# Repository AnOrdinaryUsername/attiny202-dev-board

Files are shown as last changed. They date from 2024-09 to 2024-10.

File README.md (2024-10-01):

# ATtiny202 Dev Board

A small development board for the ATtiny202 microcontroller and my first PCB!

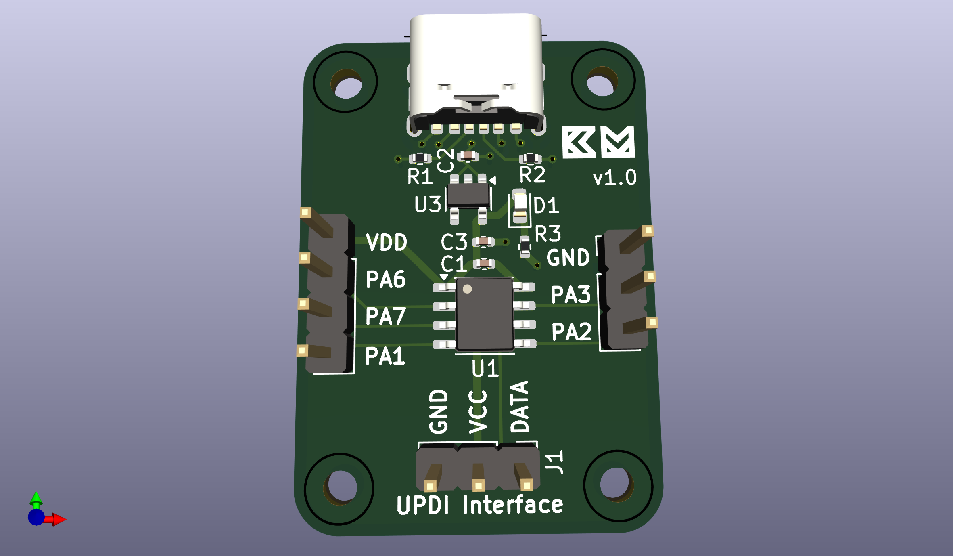
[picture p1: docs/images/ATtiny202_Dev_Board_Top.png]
PCB Top View


## Features

- Power-Only USB Type-C Receptacle
- 3.3V LDO Voltage Regulator
- Red Power On LED Indicator
- UPDI Interface

## Programming

Programmable using [SerialUPDI](https://github.com/SpenceKonde/AVR-Guidance/blob/master/UPDI/jtag2updi.md) (recommended)
or [jtag2updi](https://github.com/ElTangas/jtag2updi).

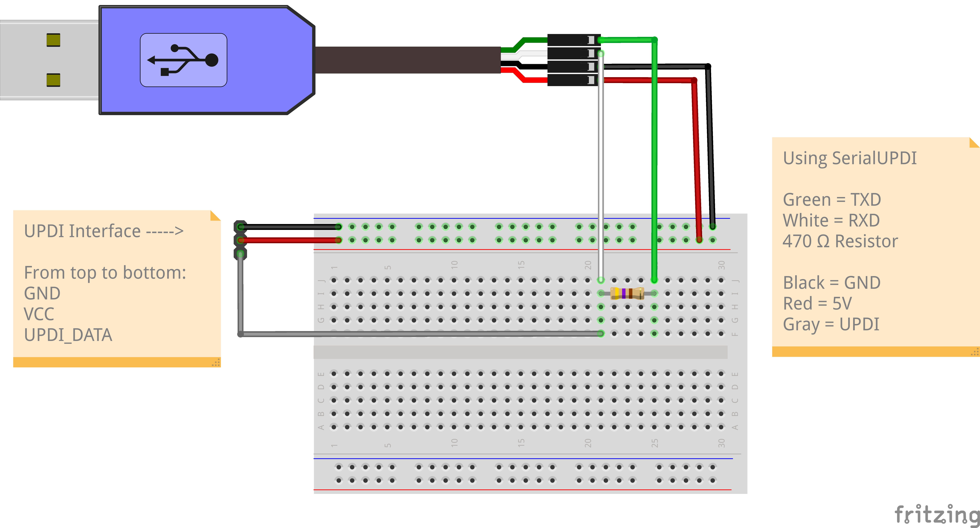
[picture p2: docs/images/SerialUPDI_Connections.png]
SerialUPDI Connections


Install avrdude following these [instructions](https://github.com/avrdudes/avrdude/wiki/Building-AVRDUDE-for-Linux) on their GitHub. Don't install through your system's package manager, or you'll get an older version of avrdude that doesn't have SerialUPDI. 

Before you can use avr-gcc to build the program, you must first download the device-pack files
from [Microchip's Packs Repository](https://packs.download.microchip.com/). Download the one that
says `Microchip ATtiny Series Device Support (3.1.260)` and then unzip it to a directory of your
choice.

```
mkdir atpack
mv Microchip.ATtiny_DFP.3.1.260.atpack atpack
cd atpack && unzip Microchip.ATtiny_DFP.3.1.260.atpack
```

You can now build specific projects using the `Makefile`

```
make build proj=blinky atpack=~/atpack/
```

Or build all projects

```
make
```

After you've built your project and connected the USB to TTL adapter to your PC and the UPDI interface, 
upload the build files using avrdude.

```
avrdude -vvv -c serialupdi -b 230400 -P /dev/ttyUSB0 -p t202 -U flash:w:your_build_file.hex:a
```

Breaking it down (better explanation at [avrdude docs](https://avrdudes.github.io/avrdude/8.0/avrdude_4.html#Option-Descriptions)):
- `-vvv` Enables verbose output
- `-c` Specifies the programmer to be used
- `-b` Sets the baud rate
- `-P` Selects which port to use
- `-p` Says which microcontroller we're programming for (t202 stands for ATtiny202). You can view the list of parts supported at [D. List of Parts](https://avrdudes.github.io/avrdude/8.0/avrdude_45.html#List-of-Parts)
- `-U` Write the hex file to flash memory and auto-detect the file format (usually Intel Hex)

Alternatively, you can also use the `Makefile`:

```
make upload proj=blinky port=/dev/ttyUSB0
```

## Schematic

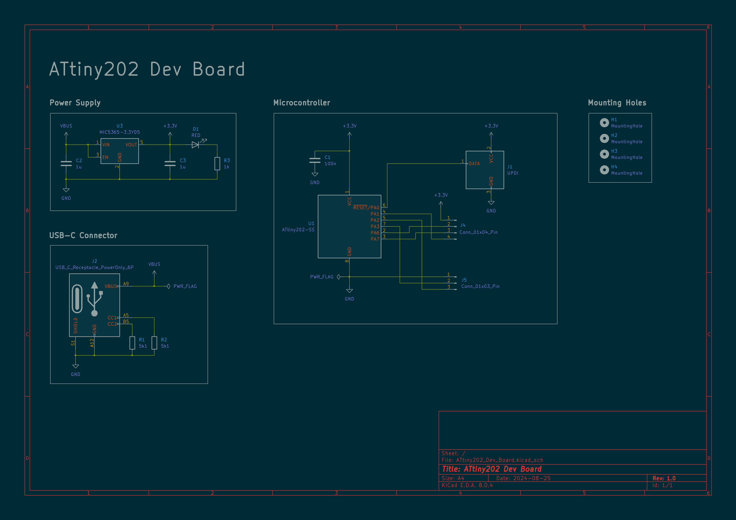
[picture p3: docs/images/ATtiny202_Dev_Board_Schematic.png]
Board Schematic


## Manufacturing/Assembly

JLCPCB formatted BOM, CPL, and Gerber files can be found in [hardware](/hardware).

Here's how the fully assembled PCB looks.

Top             |  Bottom
:-------------------------:|:-------------------------:
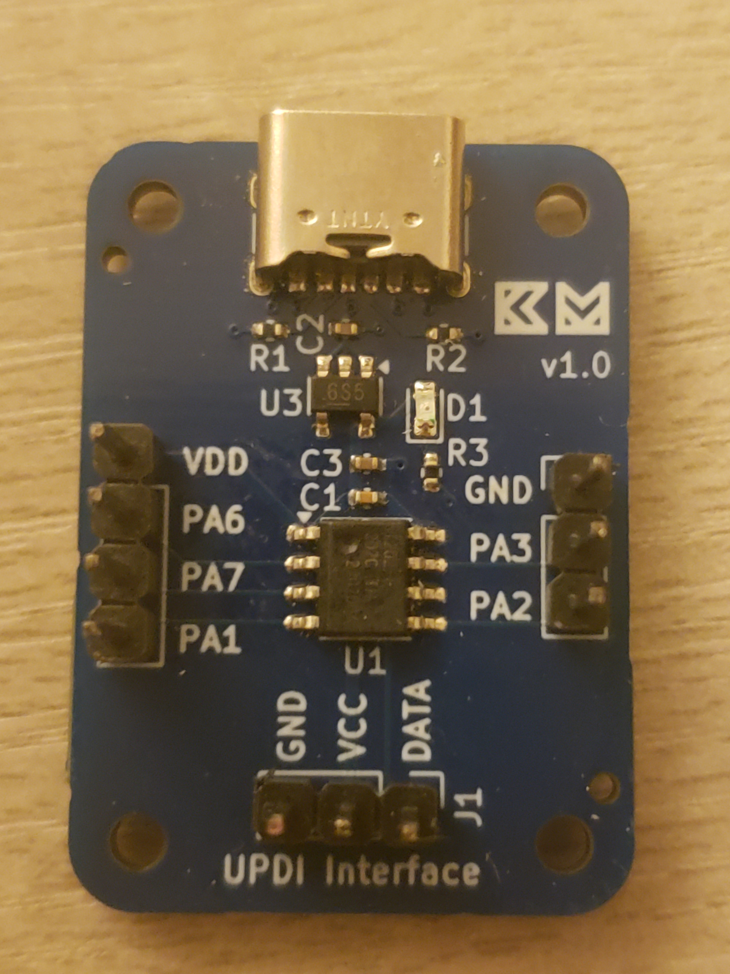
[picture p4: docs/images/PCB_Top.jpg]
Top View of PCB
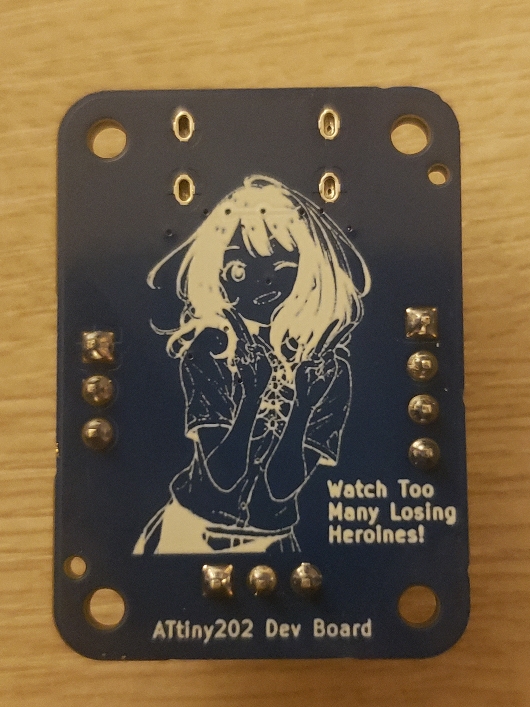
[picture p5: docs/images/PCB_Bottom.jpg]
Bottom View of PCB
 |

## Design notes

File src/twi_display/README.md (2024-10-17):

# TWI Example w/ LCD 1602

> I recommend reading A Basic Guide to I2C from Texas Instruments

Formula for SCL frequency from `25.3.4.2 TWI Master Operation`. Before starting
TWI as master, we have to set the baud rate and solve for BAUD.

```math
f_{SCL} = \frac{f_{CLK\_PER}}{10 + 2 BAUD + f_{CLK\_PER} * T_{RISE}}
```

To solve for BAUD, just plug in the values:
- CPU Clock is set to 10 MHz
- SCL is 100 kHz because we're using standard mode
- tRISE is from `31.10 I/O Pin Characteristics`

```math
\begin{multline}
\frac{f_{CLK\_PER}}{{f_{SCL}}} = 10 + 2 BAUD + f_{CLK\_PER} * T_{RISE} \\
\frac{10 MHz}{100 kHz} = 10 + 2 BAUD + 10 MHz * 2.5 ns \\
BAUD = 44.9875 \approx 45
\end{multline}
```

Minimum pullup can be calculated with the following formula.
Values taken from `Table 31-18. TWI - Timing Characteristics`.

```math
R_{P}(min) = \frac{VCC - V_{OL}(max)}{I_{OL}}
           = \frac{3.3-0.4}{3 mA}
           \approx 967 Ω
```

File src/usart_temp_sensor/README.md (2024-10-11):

# USART Example w/ On-Chip Temperature Sensor

A basic USART example that transfers on-chip temperature sensor data to your PC's terminal every
time you press a push button.

```bash
> cat /dev/ttyUSB0
Temperature (C): 27

Turning LED on

Turning LED off
```

If your sensor doesn't seem to output the right values, this could be the issue (from Errata).

Screenshot (23)

## Programming

See [programming section](https://github.com/AnOrdinaryUsername/attiny202-dev-board/blob/master/README.md#programming).

## Connections

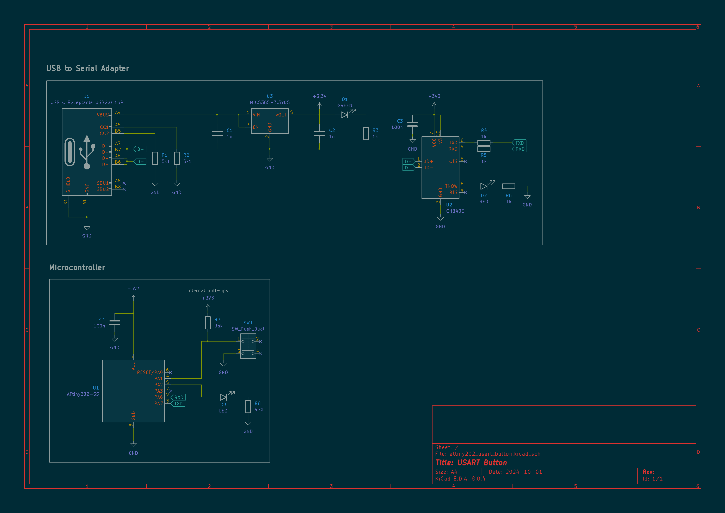
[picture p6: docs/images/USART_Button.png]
USART Button Schematic


Using a USB to Serial Adapter, make the following connections to a breadboard:
- Connect 3.3V/5V to Breadboard +
- GND to Breadboard -

On the breadboard:
- Add a button + LED with 470Ω resistor
- Breadboard - to any button pin and cathode of LED

With the dev board connect:
- VDD to Breadboard +
- GND to Breadboard -
- PA6 pin (TXD) to RXD of USB to Serial Adapter
- PA7 pin (RXD) to TXD of USB to Serial Adapter
- PA1 on button pin (near the one that was connected to ground)
- PA2 to anode of LED

Connect the adapter to your PC then run the following command

```bash
cat /dev/ttyUSB0
```

or

```bash
screen /dev/ttyUSB0 9600
```

To turn LED on or off, run
```
echo "y" > /dev/ttyUSB0
echo "n" > /dev/ttyUSB0
```

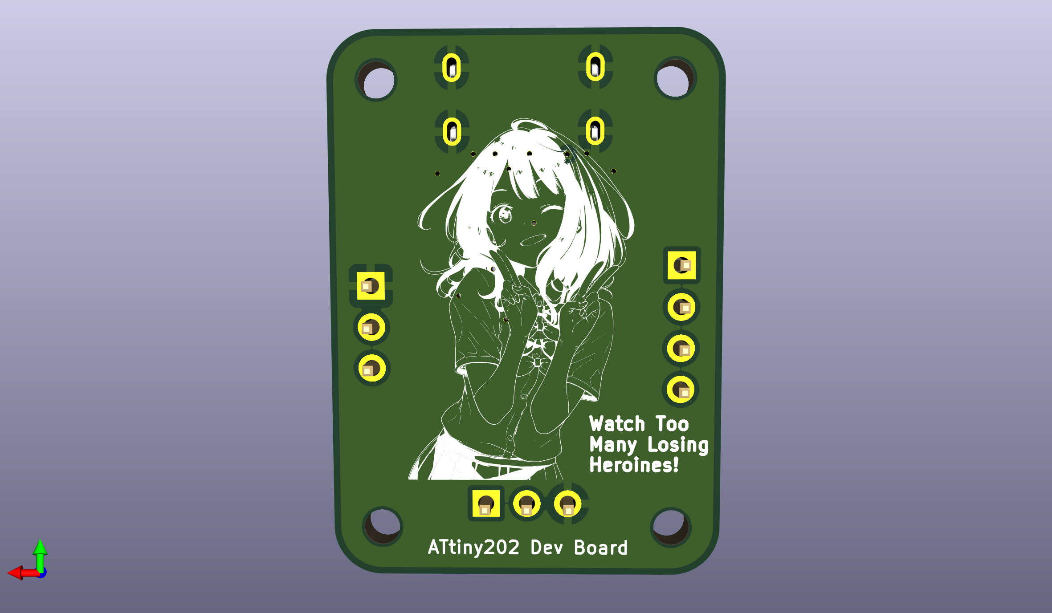
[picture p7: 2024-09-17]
docs/images/ATtiny202_Dev_Board_Bottom.png

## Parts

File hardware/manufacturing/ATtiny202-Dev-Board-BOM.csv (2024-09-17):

Comment | Designator | Qty | Footprint | JLCPCB Part #
100n | C1 | 1 | Capacitor_SMD:C_0402_1005Metric | C387941
1u | C2,C3 | 2 | Capacitor_SMD:C_0402_1005Metric | C76999
1k | R3 | 1 | Resistor_SMD:R_0402_1005Metric | C106235
5k1 | R1,R2 | 2 | Resistor_SMD:R_0402_1005Metric | C138073
ATtiny202-SS | U1 | 1 | Package_SO:SOIC-8_3.9x4.9mm_P1.27mm | C616039
Conn_01x03_Pin | J5 | 1 | Connector_PinHeader_2.54mm:PinHeader_1x03_P2.54mm_Vertical | C5360899
Conn_01x04_Pin | J4 | 1 | Connector_PinHeader_2.54mm:PinHeader_1x04_P2.54mm_Vertical | C5116483
MIC5365-3.3YD5 | U3 | 1 | Package_TO_SOT_SMD:SOT-23-5 | C626098
RED | D1 | 1 | LED_SMD:LED_0603_1608Metric | C2286
UPDI | J1 | 1 | Connector_PinHeader_2.54mm:PinHeader_1x03_P2.54mm_Vertical | C5360899
USB_C_Receptacle_PowerOnly_6P | J2 | 1 | Connector_USB:USB_C_Receptacle_GCT_USB4125-xx-x_6P_TopMnt_Horizontal | C456012

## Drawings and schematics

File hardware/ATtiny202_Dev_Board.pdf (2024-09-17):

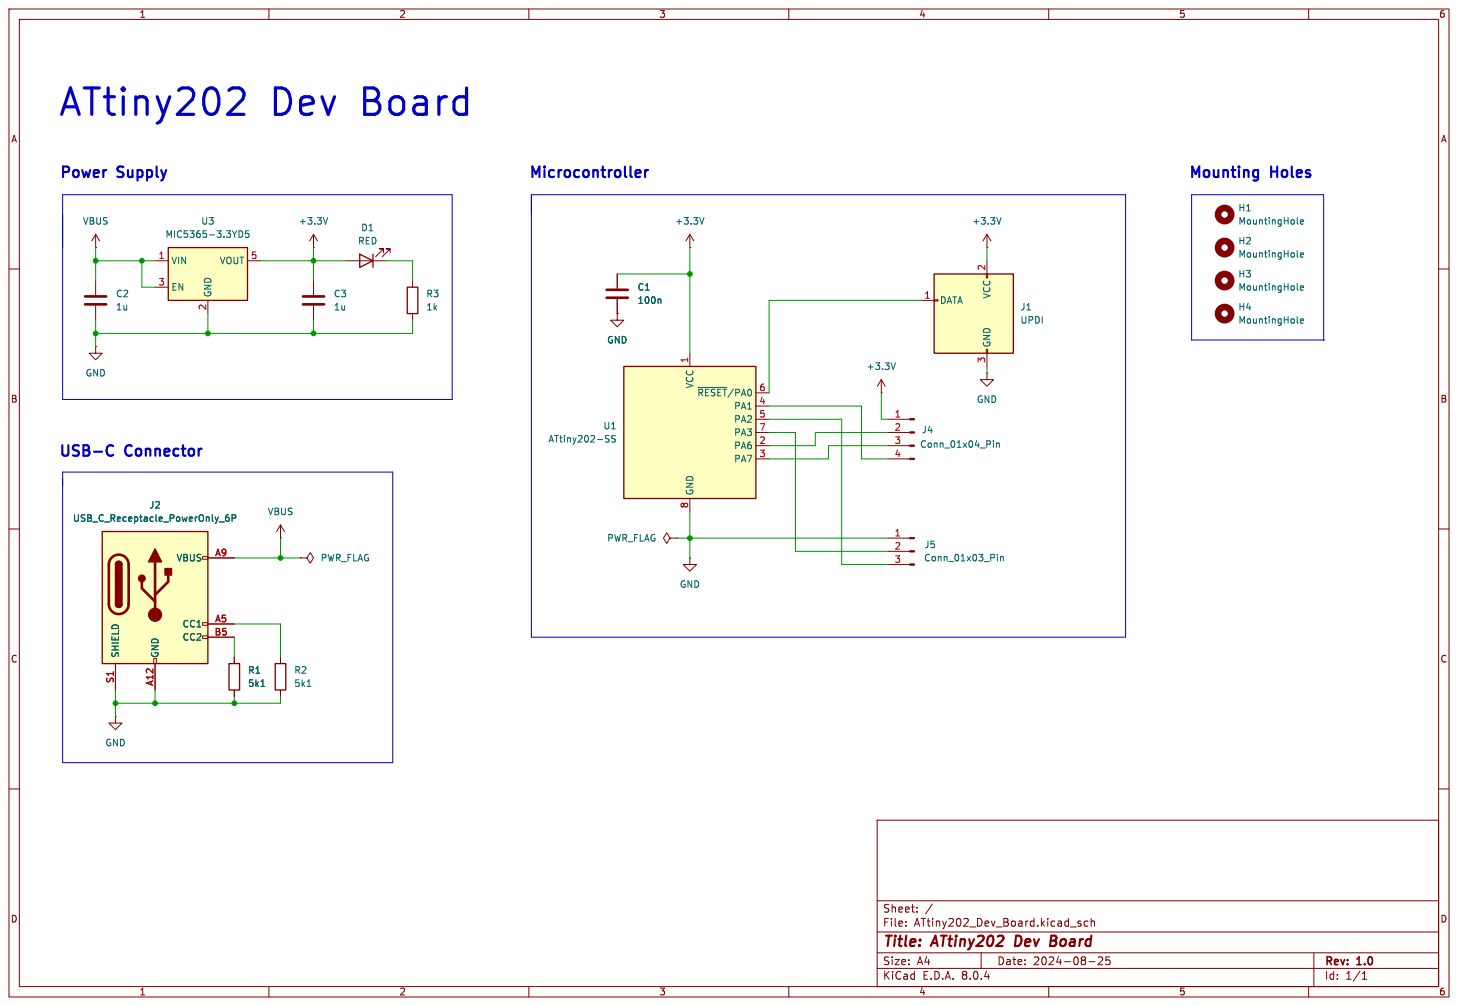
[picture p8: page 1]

File: ATtiny202_Dev_Board.kicad_sch Sheet: /
Id: 1/1 Title: ATtiny202 Dev Board

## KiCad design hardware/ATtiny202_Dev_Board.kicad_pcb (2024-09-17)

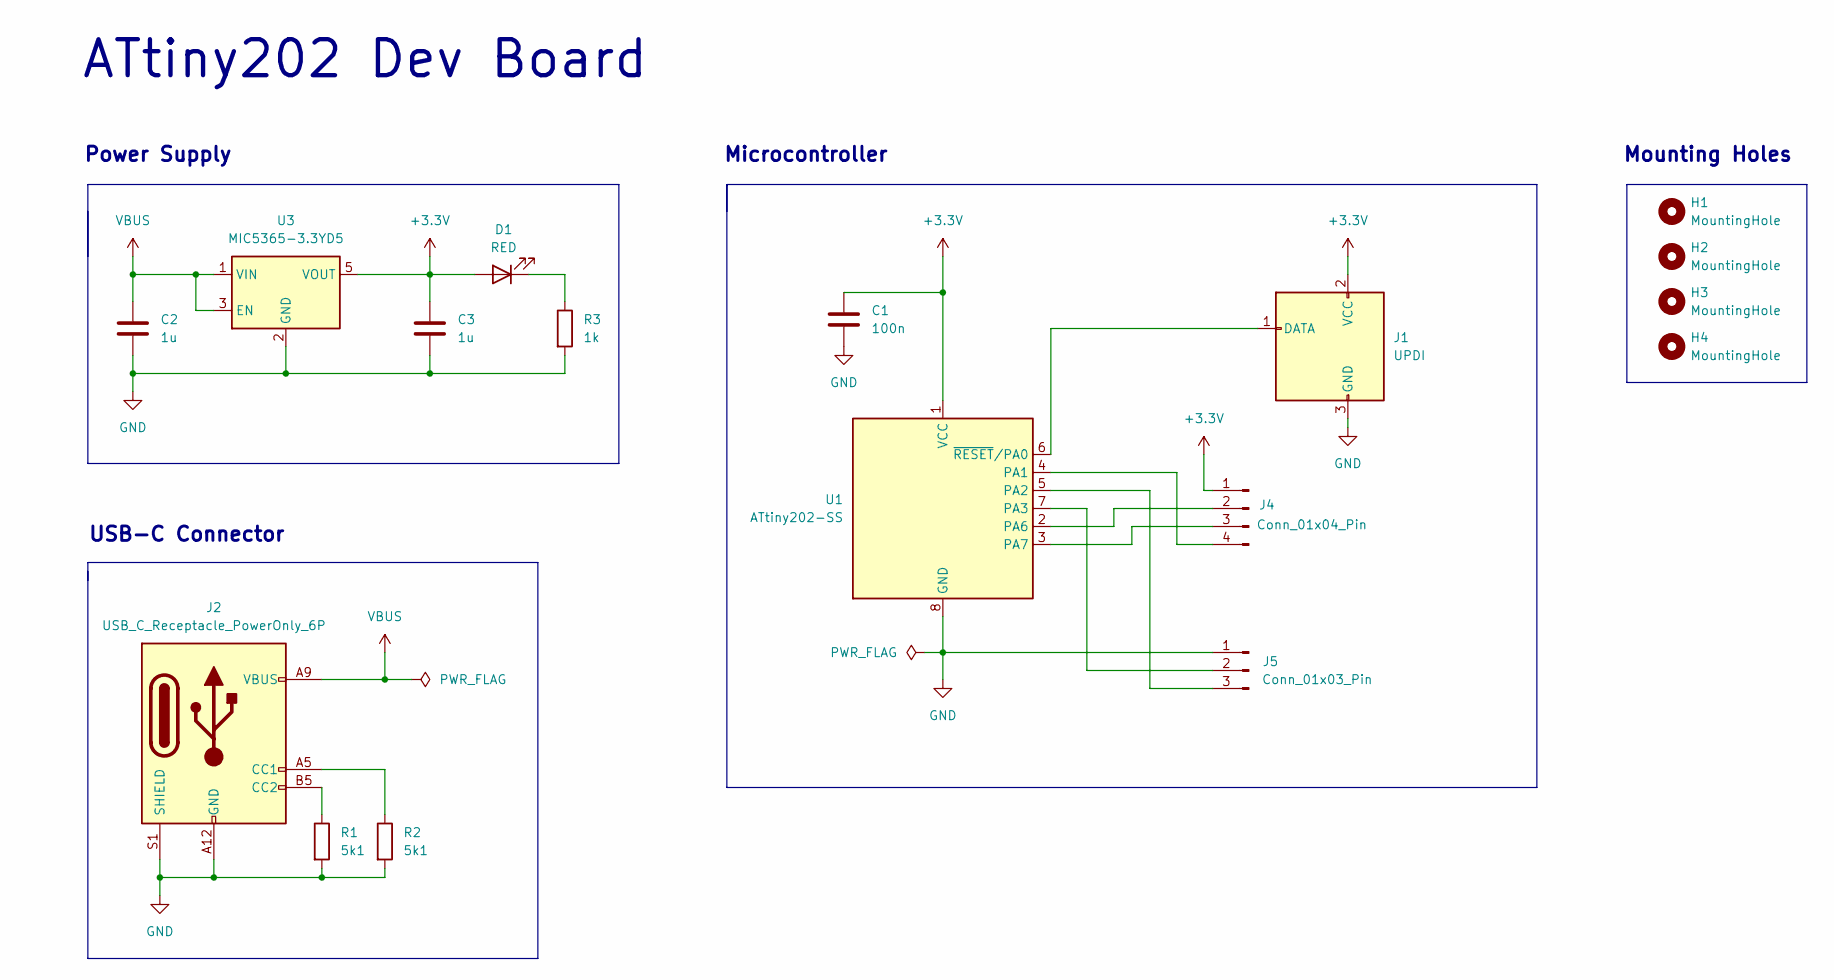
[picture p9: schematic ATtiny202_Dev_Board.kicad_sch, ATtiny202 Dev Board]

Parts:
C1: 100n; C_0402_1005Metric; JLCPCB Part # C387941
C2, C3: 1u; C_0402_1005Metric; JLCPCB Part # C76999
D1: RED; LED_0603_1608Metric; JLCPCB Part # C2286
H1, H2, H3, H4: MountingHole; MountingHole_2.2mm_M2
J1: UPDI; PinHeader_1x03_P2.54mm_Vertical; JLCPCB Part # C5360899
J2: USB_C_Receptacle_PowerOnly_6P; USB_C_Receptacle_GCT_USB4125-xx-x_6P_TopMnt_Horizontal; JLCPCB Part # C456012
J4: Conn_01x04_Pin; PinHeader_1x04_P2.54mm_Vertical; JLCPCB Part # C5116483
J5: Conn_01x03_Pin; PinHeader_1x03_P2.54mm_Vertical; JLCPCB Part # C5360899
R1, R2: 5k1; R_0402_1005Metric; JLCPCB Part # C138073
R3: 1k; R_0402_1005Metric; JLCPCB Part # C106235
U1: ATtiny202-SS; SOIC-8_3.9x4.9mm_P1.27mm; JLCPCB Part # C616039
U3: MIC5365-3.3YD5; SOT-23-5; JLCPCB Part # C626098

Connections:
+3.3V: C1.1, C3.1, D1.2 (A), J1.2 (VCC), J4.1, U1.1 (VCC), U3.5 (VOUT)
GND: C1.2, C2.2, C3.2, J1.3 (GND), J2.A12 (GND), J2.B12 (GND), J2.S1 (SHIELD), J5.1, R1.2, R2.2, R3.2, U1.8 (GND), U3.2 (GND)
unnamed: D1.1 (K), R3.1
unnamed: J1.1 (DATA), U1.6 (~RESET/PA0)
unnamed: J2.A5 (CC1), R2.1
unnamed: J2.B5 (CC2), R1.1
unnamed: J4.2, U1.2 (PA6)
unnamed: J4.3, U1.3 (PA7)
unnamed: J4.4, U1.4 (PA1)
unnamed: J5.2, U1.7 (PA3)
unnamed: J5.3, U1.5 (PA2)
VBUS: C2.1, J2.A9 (VBUS), J2.B9 (VBUS), U3.1 (VIN), U3.3 (EN)

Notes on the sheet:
Microcontroller
USB-C Connector
Power Supply
Mounting Holes
ATtiny202 Dev Board

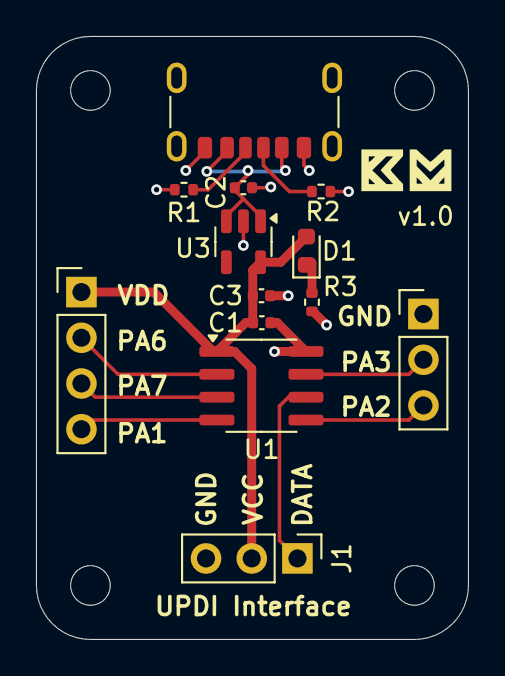
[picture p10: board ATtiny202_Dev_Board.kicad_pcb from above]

Board: 2 copper layers, 24.0 x 33.5 mm, 17 parts (0 on the bottom side), 12 nets.

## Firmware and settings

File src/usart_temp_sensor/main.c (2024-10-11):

#define F_CPU 10000000UL
#define USART0_BAUD_RATE(BAUD_RATE) ((float)(F_CPU * 64 / (16 * (float) BAUD_RATE)) + 0.5)
#include <avr/io.h>
#include <avr/interrupt.h>
#include <util/delay.h>
#include <string.h>


// Declaring function prototypes as static saves 24 bytes
static void USART0_init(void);
static char USART0_readChar(void);
static void USART0_sendChar(char c);
static void USART0_sendString(char* str);
static int16_t read_temperature_sensor(void);
static void reverse(char* str, uint8_t length);
static char* itoa(int16_t num, char* str);
static char capitalize(char c);
static void LED_init(void);
static void LED_on(void);
static void LED_off(void);


char sensor_buffer[20];

// Every time, PA1 transitions from a high-to-low state (by pressing a button),
// send on-chip temperature sensor data to PC.
ISR(PORTA_PORT_vect) {
     // Check if the interrupt was caused by PA1
    if (PORTA.INTFLAGS & PIN1_bm) {
        int16_t temp = read_temperature_sensor();
        USART0_sendString("Temperature (C): ");
        USART0_sendString(itoa(temp, sensor_buffer));
        USART0_sendString("\r\n");
        _delay_ms(100);

        // Clear the interrupt flag
        PORTA.INTFLAGS = PIN1_bm;
    }
}

int main(void) {
    _PROTECTED_WRITE(CLKCTRL_MCLKCTRLB, CLKCTRL_PDIV_2X_gc | CLKCTRL_PEN_bm);
   
    char pc_char;

    _delay_ms(10);
    USART0_init();
    LED_init();


    // Set Pin 1 in Port A as input
    PORTA.IN = PIN1_bm;

    // Enable internal pull-up resistor for PA1
    // See 16.5.11 and Table 31-15. I/O Pin Characteristics
    PORTA.PIN1CTRL = PORT_PULLUPEN_bm | PORT_ISC_FALLING_gc;

    // Enable global interrupts
    sei();

    while (1) {
        pc_char = capitalize(USART0_readChar());        

        // To turn LED on or off send "Y" or "N" to USB port
        if (pc_char == 'Y') {
            LED_on();
            USART0_sendString("Turning LED on\r\n");

            // Debounce delay
            _delay_ms(100);
        } else if (pc_char == 'N') {
            LED_off();
            USART0_sendString("Turning LED off\r\n");

            // Debounce delay
            _delay_ms(100);
        }
    }
}

void USART0_init(void) {
    PORTA.DIR &= ~PIN7_bm; // RXD
    PORTA.DIR |= PIN6_bm; // TXD

    USART0.BAUD = (uint16_t) USART0_BAUD_RATE(9600);
    USART0.CTRLB = USART_TXEN_bm | USART_RXEN_bm;
}


char USART0_readChar(void) {
    while (!(USART0.STATUS & USART_RXCIF_bm));
    return USART0.RXDATAL;
}


void USART0_sendChar(char c) {
    while (!(USART0.STATUS & USART_DREIF_bm));
    USART0.TXDATAL = c;
}


void USART0_sendString(char* str) {
    for (size_t i = 0; i < strlen(str); i++) {
        USART0_sendChar(str[i]);
    }
}

/*
 * Read the on-chip temperature sensor according to 29.3.2.6
 */
int16_t read_temperature_sensor(void) {
    // 1.  Configure the internal voltage reference to 1.1V 
    //     by configuring the in VREF peripheral.
    VREF.CTRLA = VREF_ADC0REFSEL_1V1_gc;

    // 2.  Select the internal voltage reference by writing 
    //     the REFSEL bits in ADCn.CTRLC to 0x0.
    ADC0.CTRLC = ADC_PRESC_DIV32_gc | ADC_REFSEL_INTREF_gc | ADC_SAMPCAP_bm;

    // 3. Select the ADC temperature sensor channel by configuring the
    //    MUXPOS register (ADCn.MUXPOS). This enables the temperature sensor
    ADC0.MUXPOS = ADC_MUXPOS_TEMPSENSE_gc;

    /* 
     * 4. In ADCn.CTRLD Select INITDLY ≥ 32 µs × fCLK_ADC
     *
     * Initialization Delay before first samples ≥  32 µs * (10 MHz / 32 prescaler division factor)
     * Initialization Delay before first samples ≥ 10
     * 
     * 29.5.4 Control D lists the following delay counts: 0, 16, 32, 64, 128, 256
     * so we choose 16.
     */
    ADC0.CTRLD = ADC_INITDLY_DLY16_gc;

    // 5. In ADCn.SAMPCTRL Select SAMPLEN ≥ 32 µs × fCLK_ADC
    ADC0.SAMPCTRL = 10;

    // Enable ADC
    ADC0.CTRLA = ADC_ENABLE_bm;
    // Start conversion for a single measurement
    ADC0.COMMAND = ADC_STCONV_bm;
    // Wait for conversion to complete
    while (!(ADC0.INTFLAGS & ADC_RESRDY_bm));

    // Read signed value from signature row
    int8_t sigrow_offset = SIGROW.TEMPSENSE1;
    // Read unsigned value from signature row
    uint8_t sigrow_gain = SIGROW.TEMPSENSE0;
    // ADC conversion result with 1.1 V internal reference
    uint32_t temp = ADC0.RES - sigrow_offset;
    // Result might overflow 16 bit variable (10bit+8bit)
    temp *= sigrow_gain;
    // Add 1/2 to get correct rounding on division below
    temp += 0x80;
    // Divide result to get Kelvin 
    temp >>= 8;
    // Convert to Celsius
    temp -= 273;

    return ((int16_t) temp);
}


void reverse(char* str, uint8_t length) {
    uint8_t start = 0;
    uint8_t end = length - 1;
    while (start < end) {
        // Swap characters
        char temp = str[start];
        str[start] = str[end];
        str[end] = temp;
        start++;
        end--;
    }
}


char* itoa(int16_t num, char* str) {
    uint8_t i = 0;

    // Handle 0 case explicitly
    if (num == 0) {
        str[i++] = '0';
        str[i] = '\0';
        return str;
    }

    // Process each digit
    while (num != 0) {
        uint8_t digit = num % 10;
        // Convert digit to ASCII character
        str[i++] = digit + '0';

        num /= 10;
    }

    // Null-terminate the string
    str[i] = '\0';

    // The digits are in reverse order, so reverse the string
    reverse(str, i);

    return str;
}

char capitalize(char c) {
  uint8_t ascii_dec = (uint8_t) c;
  
  if (ascii_dec > 96 && ascii_dec < 123) {
    ascii_dec -= 32;
    return ((char) ascii_dec);
  }
  
  return c;
} 


void LED_init(void) {
    // Use PA2 as output for red LED
    PORTA.DIR |= PIN2_bm;
}


void LED_on(void) {
    PORTA.OUT |= PIN2_bm;
}


void LED_off(void) {
    PORTA.OUTCLR = PIN2_bm;
}

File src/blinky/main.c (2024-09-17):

/* 
 * Tells delay.h that our clock is at 10 MHz.
 * This DOES NOT set the CPU clock speed.
 */
#define F_CPU 10000000UL
#include <avr/io.h>
#include <util/delay.h>

int main(void) {
    /* Sets prescaler division factor to 2x and sets 
     * CPU clock speed to 10 MHz (20 MHz / 2).
     * 
     * Important because we power the device with 3.3V and don't want
     * to overclock the CPU (See Figure 31-1 pg. 477)!
     */
    _PROTECTED_WRITE(CLKCTRL_MCLKCTRLB, CLKCTRL_PDIV_2X_gc | CLKCTRL_PEN_bm);
    // Set Pin 1 in Port A as output
    // See 16.5.2
    PORTA.DIRSET = 0b00000010;
    
    while (1) {
        // Set output value of Pin 1 in Port A to High aka 1
        // See 16.5.6
        PORTA.OUTSET = 0b00000010;
        _delay_ms(500);
        // Clear the bit value of Pin 1 in Port A and set it to Low aka 0
        // See 16.5.7
        PORTA.OUTCLR = 0b00000010;
        _delay_ms(500);
    }
}

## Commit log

2024-09-17 Add manufactured PCB images
2024-09-17 Add assembled PCB images
2024-10-02 Fix fuses command
2024-10-02 Change USART example to use button as input
2024-10-02 Fix errors in Button schematic
    Previous schematic errors:
    - D2 was not a light-emitting diode
    - USB-C should be the 16p one not 14p
2024-10-04 Show actual memory usage of program build
    The size of the hex file doesn't represent size of the program
    in flash memory. Use "avr-objdump -P mem-usage" to get an
    accurate reading.
    Add way to generate assembler listings with associted C code
    and line numbers.
2024-10-11 Add ability to turn LED on/off w/ USART
    - Use LED to show how to transmit data from PC to MCU.
    - Move button code to ISR because it won't work in main
    loop otherwise.
    - Adjust schematic to show internal pull-up resistor usage
    and LED connection.
    [main.c]
2024-10-17 Show TWI/I2C math
